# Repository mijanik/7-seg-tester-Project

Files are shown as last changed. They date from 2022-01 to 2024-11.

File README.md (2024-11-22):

# 7-seg-quick-tester
Simple to use, quick and reliable tester of 4-element 7-segment (+dot) displays. 

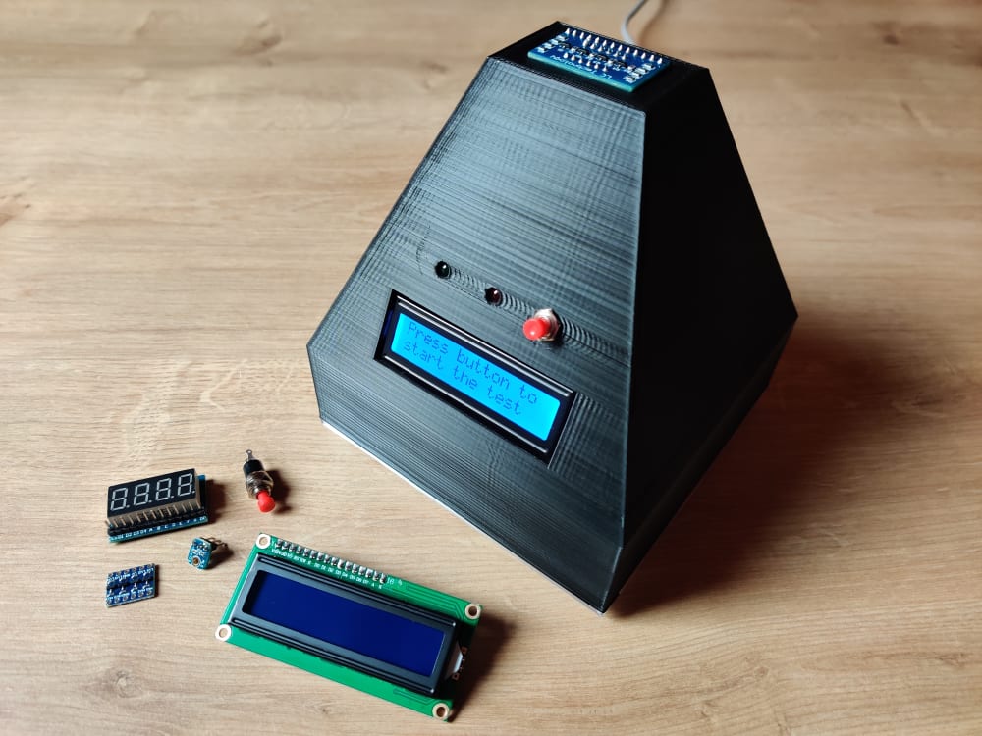
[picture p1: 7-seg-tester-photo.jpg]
7-seg-tester concept


## Purpose of the project
We are creating this project to allow quick testing of 7-seg displays used (and probably broken) by other students.

## Parts being used
For this project, we are using: 

- [x] Freescale Freedom Development Platform - Kinetis FRDM-KL05Z
- [x] 3D-printed Pyramid, well, base and pry tool
- [x] Adafruit ALS-PT19 Phototransistor
- [x] 3 Logic voltage coverters (3.3V to 5V)
- [x] LCD display 2x16
- [x] Red and green LED diodes
- [x] PS10BRD button
- [x] USB type-B breakout and plug
- [x] Screws and PCB standoffs

## Microcontroller functionality used
- Finite State Machine and SysTick for switching the test routine for each segment
- ADC to read voltage value from phototransistor
- UART to send test information to PC
- I2C to handle LCD display
- Interrupts

## Description

At the end of the semester, it is necessary to test a large number of 7-segment displays returned by students to laboratories. However, manually checking each of their segments, e.g. using a multimeter, would require a lot of work and would be prone to a validation error. Hence the idea to construct an automatic testing device that would speed up this process. The main assumptions were ease of use and speed of operation.
The tester has been enclosed in a custom-made housing made with the use of 3D printing technology. The characteristic shape of the truncated pyramid ensures a strong structure and convenient location of the most important part - the recess for the tested display, located on the top of the device. It is a small darkroom with a light intensity sensor module with a phototransistor at the bottom. By placing a display in it, we provide all electrical connections at the same time. Its walls are additionally covered with a reflective foil to facilitate detection.
On the front of the housing there is a blue LCD display informing about the currently performed activity, one button for operating the entire device, red and green LED diode indicating the test result and a USB socket for connecting to a computer or the power supply itself. The push-in base is easy to detach for easy access to the inside of the housing. There, in addition to a large number of connecting cables, there is the heart of the tester - the FRDM-KL05Z development board and 3 bi-directional logic level converters, which made it possible to control the 7-segment display using a higher voltage of 5V. Thus, its brightness was increased during the test.
To learn more about the tested display, we can connect the tester to the computer and use the connection through the UART serial port. By default, the device sends a text representation of the tested display to the computer after each test, which makes it possible to check which segments are faulty.

## Project & Authors information

###### Authors:

Miłosz Janik & Antoni Kijania

###### Subjects:

- Technika Mikroprocesorowa 2
- Design Laboratory

###### Project supervisor:

mgr inż. Sebastian Koryciak

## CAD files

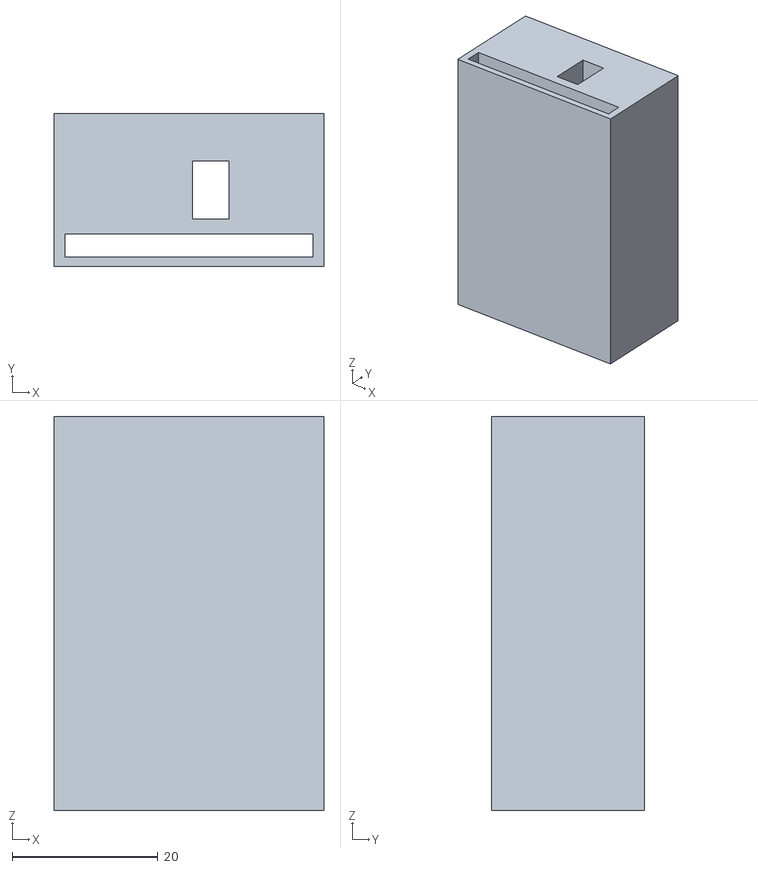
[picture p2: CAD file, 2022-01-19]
3D_Models/Display_well.stl
37.0 x 21.0 x 54.0

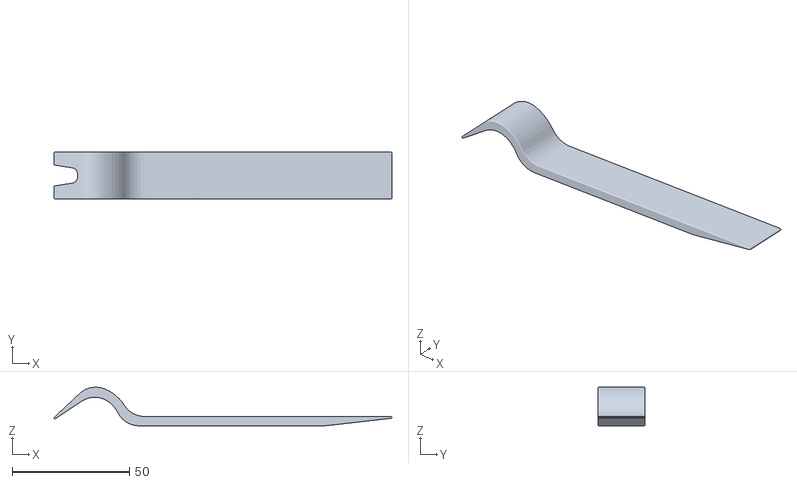
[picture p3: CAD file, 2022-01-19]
3D_Models/Pry_tool.STL
143.9 x 20.0 x 16.5

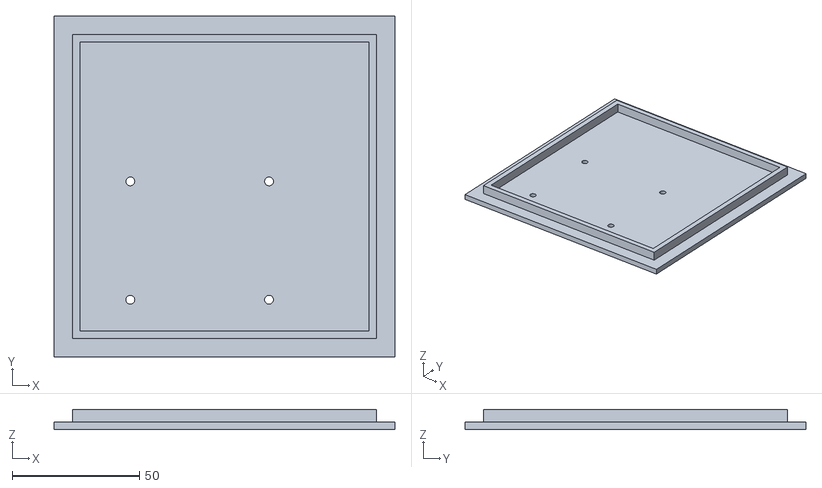
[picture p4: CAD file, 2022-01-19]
3D_Models/Base.stl
134.0 x 134.0 x 8.00

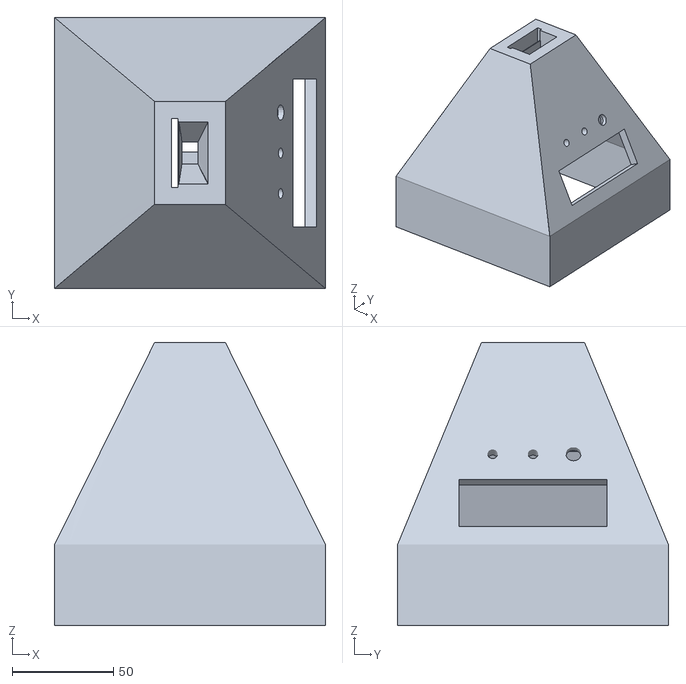
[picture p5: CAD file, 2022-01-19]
3D_Models/Pyramid.stl
134.0 x 134.0 x 140.0

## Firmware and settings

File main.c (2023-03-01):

/**
* @file main.c
* @authors Milosz Janik & Antoni Kijania
* @date Jan 2022
* @brief File containing the main function.
* @ver 1.2
*/				

#include "MKL05Z4.h"
#include "fsm.h"
#include "buttons.h"
#include "led.h"
#include "uart0.h"

void SysTick_Handler(void) {
	nextFSMState();											
}

int main (void){
	
	//Initialization
	LED_Init();
	buttonsInitialize();
	UART0_Init();
	fsmInitialize();
	SysTick_Config(SystemCoreClock / /*20*/20);
	
	while(1){
	__WFI(); // Wait for interrupt
	}
}

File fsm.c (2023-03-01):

#include "MKL05Z4.h"
#include "frdm_bsp.h"
#include "fsm.h"
#include "led.h"
#include "ADC.h"
#include "lcd1602.h"
#include <stdio.h>
#include "buttons.h"
#include "uart0.h"

float volt_coeff = ((float)(((float)2.91) / 4095) );			//ADC to voltage conversion
uint8_t wynik_ok=0;
uint16_t temp;
float	wynik;
char display[]={0x20,0x20,0x20,0x20,0x20,0x20,0x20,0x20,0x20,0x20,0x20,0x20,0x20,0x20,0x20,0x20,0x20};

//Automatic mode - ADC
void ADC0_IRQHandler(){	
	temp = ADC0->R[0];						// Read value
	if(!wynik_ok){								// Check if the result was read by the main loop
		wynik = temp;								// Send new data to main loop
		wynik_ok=1;									// Set "result updated" flag
	}
	NVIC_EnableIRQ(ADC0_IRQn);
}


//Current FSM state flags
typedef enum {
	State_0_clear,								// FSM state - clear variables
	State_1_Wait_for_button,			// FSM state - Wait for user to press the button to start
  State_2_LED_ON,								// FSM state - Power on chosen segment on chosen display (dependent on flag)
  State_3_ADC,									// FSM state - Read 10 samples from ADC, calculate average
	State_4_Compare,							// FSM state - Compare average values with defined values
	State_5_LED_OFF,							// FSM state - Power off chosen segment on chosen display (dependent on flag)
	State_6_Inc_disp_seg,					// FSM state - Increment segment or display flag + Check segment and display flag values and take action
	State_7_UART						 		  // FSM state - Send all measurments to PC
	
} FSMStateType;
static FSMStateType fsmState;		//variable containing current FSM state



//Function declarations
void nextFSMState(void);
FSMStateType state_0(void);
FSMStateType state_1(void);
FSMStateType state_2(void);
FSMStateType state_3(void);
FSMStateType state_4(void);
FSMStateType state_5(void);
FSMStateType state_6(void);
FSMStateType state_7(void);

//FSM control variables

static unsigned int count_display = 0;
static unsigned int count_segment = 0;

double measurements[100];
double avg_meas;
double measurement_memory[32];
int count_measurement;
double ref_brightness[32] = {0.008, 0.011, 0.011, 0.013, 0.022, 0.016, 0.010, 0.0007107, 0.010, 0.013, 0.011, 0.010, 0.010, 0.011, 0.009, 0.0007107, 0.008, 0.011, 0.011, 0.012, 0.013, 0.014, 0.009, 0.0007107, 0.006, 0.026, 0.031, 0.008, 0.011, 0.011, 0.008, 0.0007107};
int flag_error[32];
int count_failed = 0;
static unsigned int flag_button_pressed = 0;

//FSM, LCD initialization
void fsmInitialize() {
	fsmState = State_0_clear;
	uint8_t	kal_error;
	LCD1602_Init();
	LCD1602_Backlight(TRUE);
		
	//ADC Calibration
	kal_error=ADC_Init();
	if(kal_error){	
		while(1);
	}
	
	//First run ADC - channel 0
	ADC0->SC1[0] = ADC_SC1_AIEN_MASK | ADC_SC1_ADCH(0);
	
	
	//Display on LCD
	sprintf(display,"Press button to");
	LCD1602_SetCursor(0,0);
	LCD1602_Print(display);	
	sprintf(display,"start the test");
	LCD1602_SetCursor(0,1);
	LCD1602_Print(display);	
}


/*----------------------------------------------------------------------------
 Function that moves FSM to phase 0 - clear variables
 *----------------------------------------------------------------------------*/

FSMStateType state_0(void){
	
		
	for(int i=0; i<32; i++){
		measurement_memory[i]=0;
		flag_error[i]=0;
	}
	
	count_failed = 0;
	count_display = 0;
	count_segment = 0;
	count_measurement=0;
	avg_meas = 0;

	
	return State_1_Wait_for_button;
}
/*----------------------------------------------------------------------------
 Function that moves FSM to phase 1 - Wait for user to press the button to start
 *----------------------------------------------------------------------------*/
FSMStateType state_1(void){
	//flag_button_pressed = 1;
	if (flag_button_pressed == 0){ 					//Read START button
		return State_1_Wait_for_button;
	}
	else

	sprintf(display,"Testing ...     ");
	LCD1602_SetCursor(0,0);
	LCD1602_Print(display);	
	sprintf(display,"                ");
	LCD1602_SetCursor(0,1);
	LCD1602_Print(display);	
	
	PTA->PDOR &= ~(1<<11);//GREEN LED OFF
	PTA->PDOR &= ~(1<<9);//RED LED OFF
	
		return State_2_LED_ON;
}

/*----------------------------------------------------------------------------
 Function that moves FSM to phase 2 - Power on chosen segment on chosen display (dependent on flag)
 *----------------------------------------------------------------------------*/
FSMStateType state_2(void){
	flag_button_pressed = 0;
	DISP_Select(count_display);
	LED_Ctrl(count_segment, LED_ON);
	
	return State_3_ADC;			
}

/*----------------------------------------------------------------------------
 Function that moves FSM to phase 3 - Read 10 samples from ADC, calculate average
 *----------------------------------------------------------------------------*/
FSMStateType state_3(void){
	
	for(int i=0; i<100;i++){
		measurements[i]=0;
  }

	for(int i=0; i<100;){
		if(wynik_ok){
		wynik = wynik*volt_coeff;						// Adjust voltage
		measurements[i] = wynik;
		wynik_ok=0;                 				//set flag - confirm read ADC result
		i++;
		}
	}
	return State_4_Compare;
}

/*----------------------------------------------------------------------------
 Function that moves FSM to phase 4 - Compare average values with defined values
 *----------------------------------------------------------------------------*/
FSMStateType state_4(void){
	
	avg_meas = 0;
	//Calulate and save average brightness value
	for(int i=1; i<100;i++){
		avg_meas += measurements[i];
	}
	avg_meas /= 99;
	measurement_memory[count_measurement]=avg_meas;
	
	//Compare display brightness with reference brightness
	if(measurement_memory[count_measurement]<ref_brightness[count_measurement]){
		flag_error[count_measurement]=1;
	}
	
	count_measurement++;
	return State_5_LED_OFF;
}

/*----------------------------------------------------------------------------
 Function that moves FSM to phase 5 - Power off chosen segment on chosen display (dependent on flag)
 *----------------------------------------------------------------------------*/

FSMStateType state_5(void){
	
	DISP_Select(count_display);
	LED_Ctrl(count_segment, LED_OFF);
	
	return State_6_Inc_disp_seg;
}


/*----------------------------------------------------------------------------
 Function that moves FSM to phase 6 - Display and segment switching
 *----------------------------------------------------------------------------*/


FSMStateType state_6(void){
	
	count_segment++;
	if(count_segment>7){
			count_display++;
			count_segment=0;
			if(count_display>3){
				count_measurement = 0;
				return State_7_UART;
			}
	}
		
	return State_2_LED_ON;		
}

/*----------------------------------------------------------------------------
 Function that moves FSM to phase 7 - Sending result to UART and LCD
 *----------------------------------------------------------------------------*/
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

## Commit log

2021-11-13 First prototype
    Simple 4-digit blinker
2021-12-23 Version Beta 1.0
    Working FSM, ADC, LCD, UART
2022-01-19 3D model files upload
    [Base.stl, Display_well.stl, Pry_tool.STL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]
2022-01-19 First prototype
